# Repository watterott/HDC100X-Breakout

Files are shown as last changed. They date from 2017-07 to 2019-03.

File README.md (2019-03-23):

# HDC100X-Breakout
Breakout with TI HDC1000 or HDC1008 Digital Humidity and Temperature Sensor.

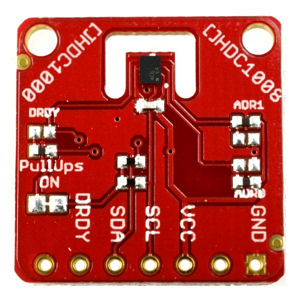
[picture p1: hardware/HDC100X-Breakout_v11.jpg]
HDC100X-Breakout


* [TI HDC1000 or HDC1008](https://www.ti.com/product/hdc1008) Digital Humidity and Temperature Sensor
* Relative Humidity (RH) operating range: 0% to 100%
* Relative Humidity accuracy: HDC1008 +/-4%, HDC1000 +/-3%
* Temperature accuracy: +/-0.2°C
* TWI/I2C Interface (address: 0x43 with ADR0=1 and ADR1=1)
* 3.3V - 5V Power Supply and Logic Level
* Open-Source and released under the [Creative Commons Attribution Share-Alike License](https://creativecommons.org/licenses/by-sa/4.0/).
* **[Documentation on learn.watterott.com](https://learn.watterott.com)**

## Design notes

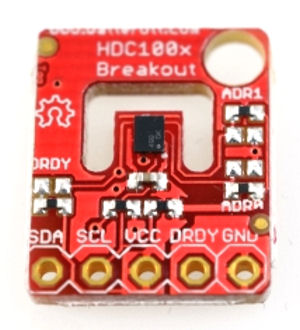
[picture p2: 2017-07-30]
hardware/HDC100X-Breakout_v10.jpg

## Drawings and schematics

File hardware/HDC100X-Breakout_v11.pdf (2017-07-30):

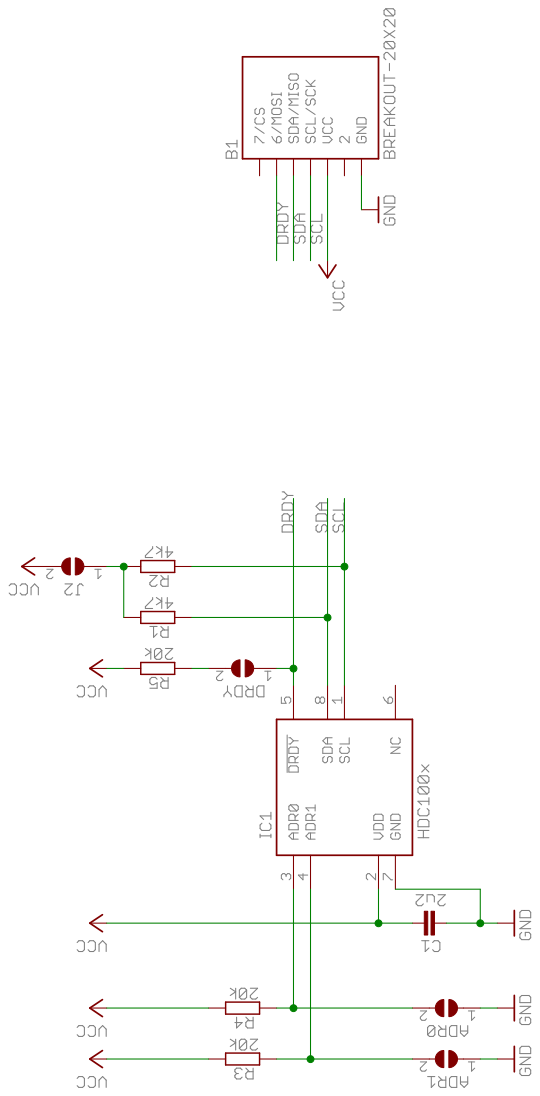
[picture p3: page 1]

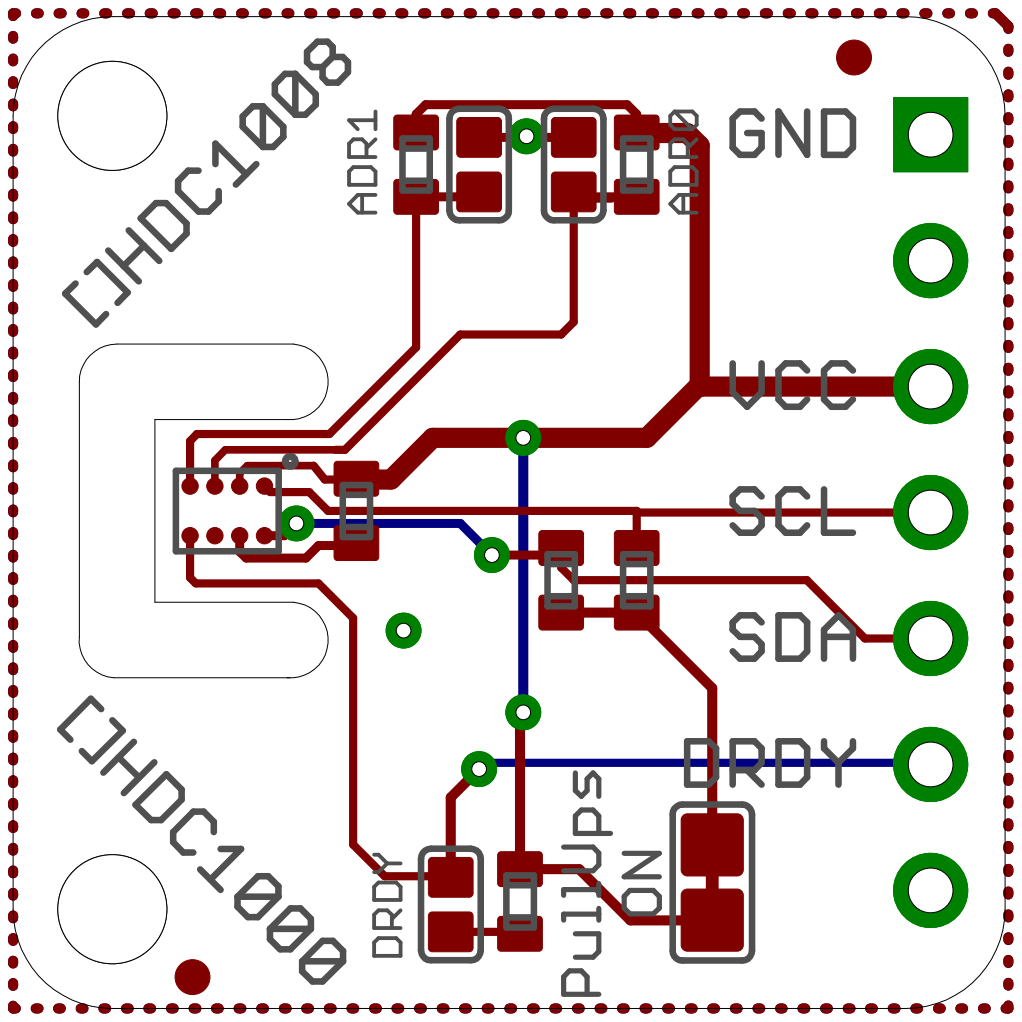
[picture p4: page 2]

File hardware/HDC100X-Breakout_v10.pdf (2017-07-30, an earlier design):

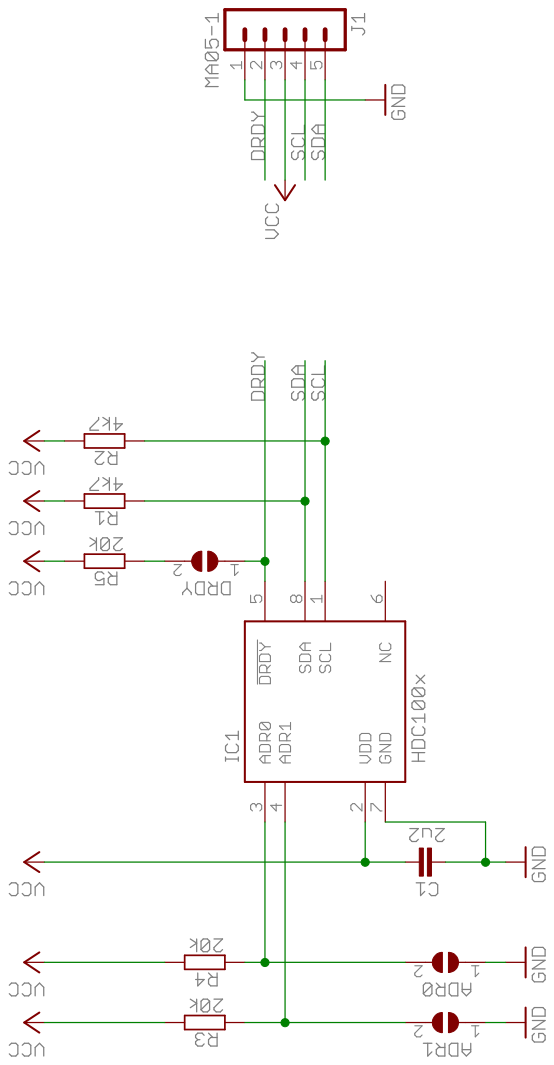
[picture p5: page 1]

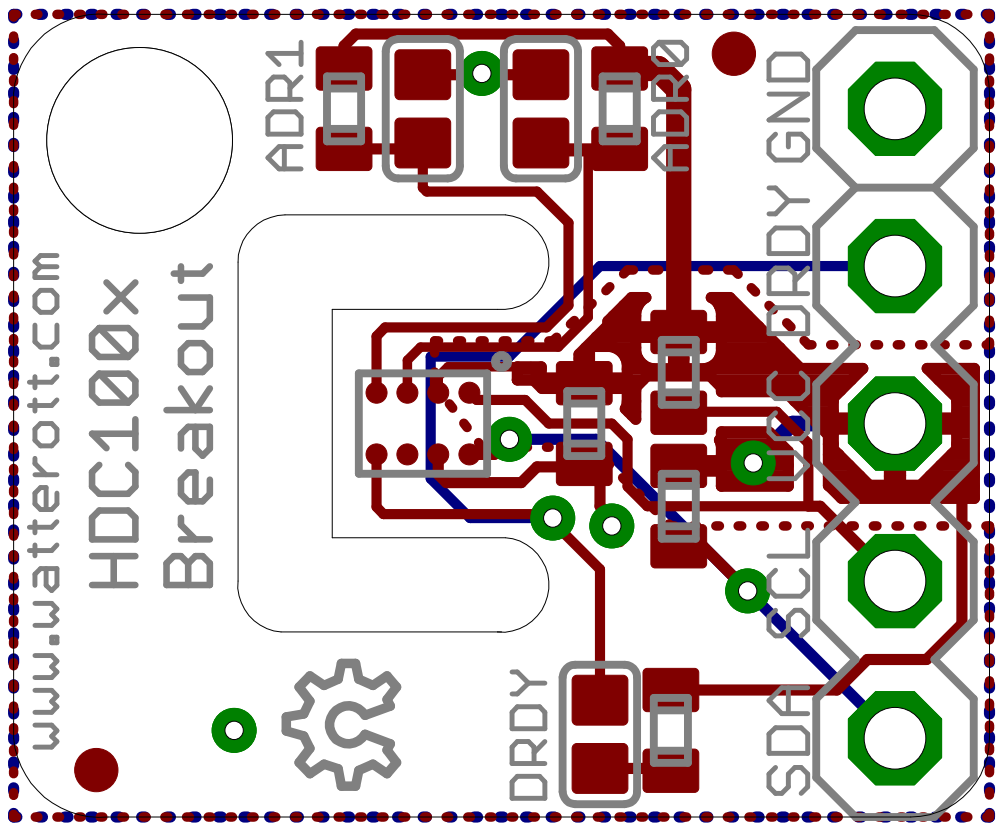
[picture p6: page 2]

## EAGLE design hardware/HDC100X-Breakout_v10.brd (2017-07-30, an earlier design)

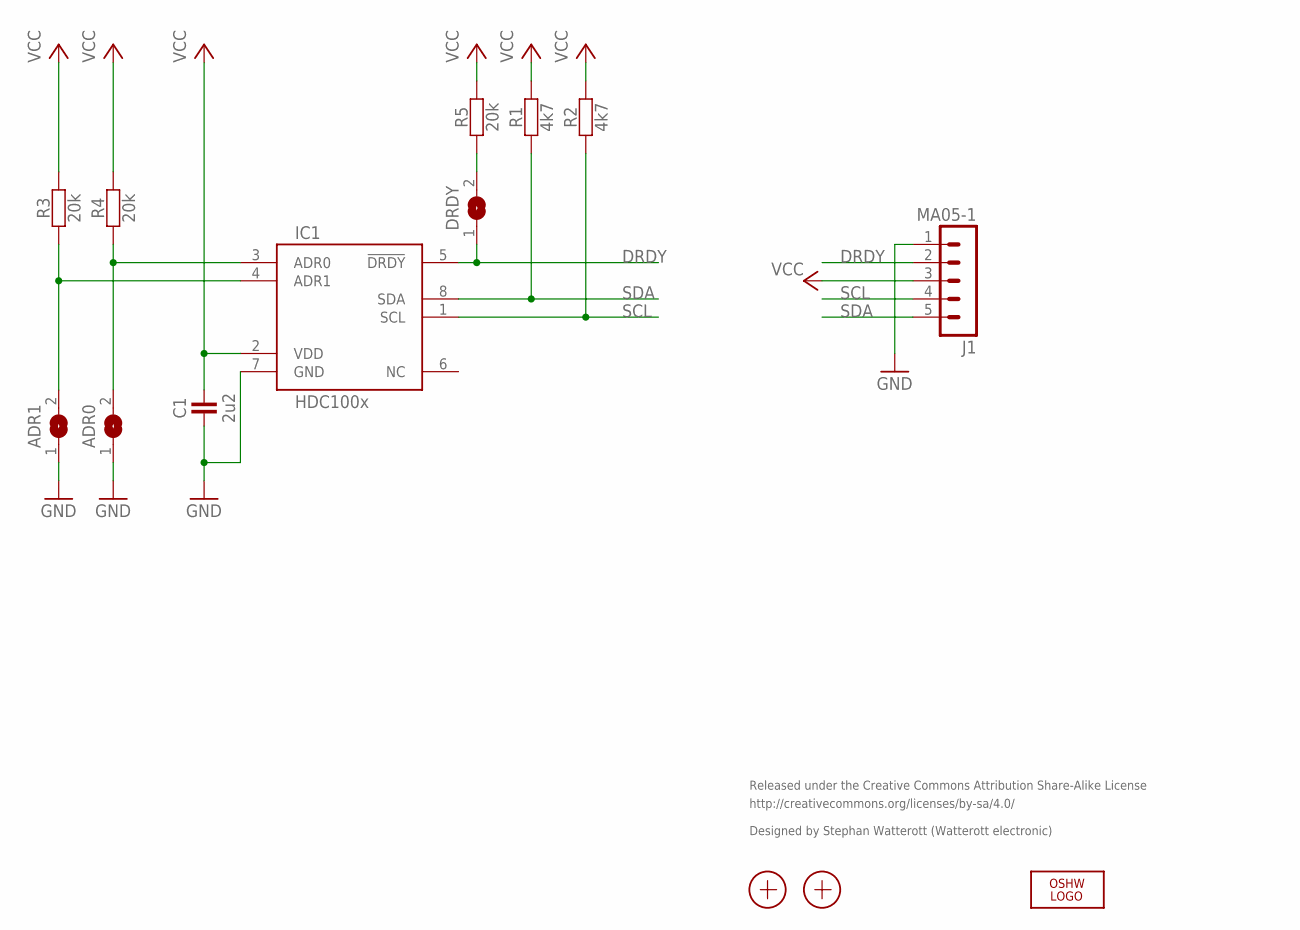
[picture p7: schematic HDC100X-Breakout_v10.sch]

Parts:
ADR0, ADR1: JUMPER2-0402
C1: 2u2; R0402
DRDY: JUMPER2-0402
IC1: HDC100x; WLCSP
J1: MA05-1
LOGO2: OSHW_LOGOX0070; OSHW_6X70
R1, R2: 4k7; R0402
R3, R4, R5: 20k; R0402
X1, X2: PASSER-07; PASSER_07MM

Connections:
ADR0: ADR0.2, IC1.3 (ADR0), R4.1
ADR1: ADR1.2, IC1.4 (ADR1), R3.1
DRDY: DRDY.1, IC1.5 (!DRDY), J1.2
GND: ADR0.1, ADR1.1, C1.1, IC1.7 (GND), J1.1
unnamed: DRDY.2, R5.1
SCL: IC1.1 (SCL), J1.4, R2.1
SDA: IC1.8 (SDA), J1.5, R1.1
VCC: C1.2, IC1.2 (VDD), J1.3, R1.2, R2.2, R3.2, R4.2, R5.2

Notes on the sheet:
Released under the Creative Commons Attribution Share-Alike License
http://creativecommons.org/licenses/by-sa/4.0/
Designed by Stephan Watterott (Watterott electronic)

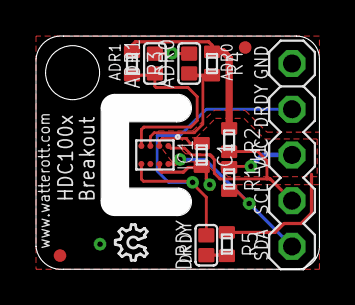
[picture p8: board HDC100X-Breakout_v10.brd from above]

Board: 2 copper layers, 15.7 x 13.0 mm, 14 parts (0 on the bottom side), 8 nets.

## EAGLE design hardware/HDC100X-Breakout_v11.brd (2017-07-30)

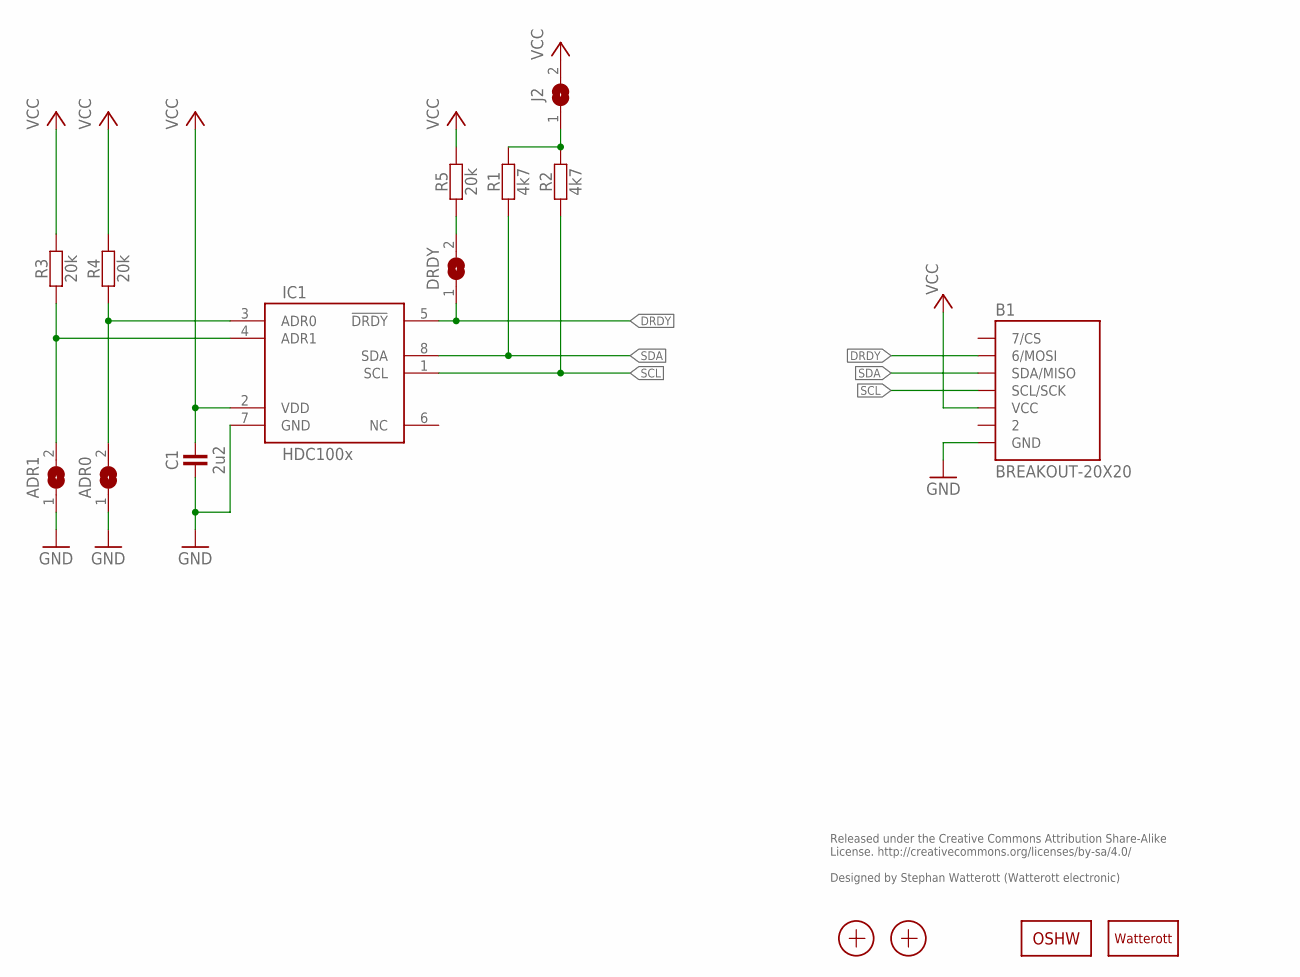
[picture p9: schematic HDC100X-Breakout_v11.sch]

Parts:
ADR0, ADR1: JUMPER2-0402
B1: BREAKOUT-20X20
C1: 2u2; R0402
DRDY: JUMPER2-0402
IC1: HDC100x; WLCSP
J2: JUMPER2-0603
LOGO2: OSHW_LOGOX0070; OSHW_6X70
LOGO3: LOGO-S_PLACE_M; SPARK_TPLACE_M
R1, R2: 4k7; R0402
R3, R4, R5: 20k; R0402
X1, X2: PASSER-07; PASSER_07MM

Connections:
ADR0: ADR0.2, IC1.3 (ADR0), R4.1
ADR1: ADR1.2, IC1.4 (ADR1), R3.1
DRDY: B1.MOSI (6/MOSI), DRDY.1, IC1.5 (!DRDY)
GND: ADR0.1, ADR1.1, B1.GND, C1.1, IC1.7 (GND)
unnamed: J2.1, R1.2, R2.2
unnamed: DRDY.2, R5.1
SCL: B1.SCL/SCK, IC1.1 (SCL), R2.1
SDA: B1.SDA/MISO, IC1.8 (SDA), R1.1
VCC: B1.VCC, C1.2, IC1.2 (VDD), J2.2, R3.2, R4.2, R5.2

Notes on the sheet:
Released under the Creative Commons Attribution Share-Alike License. http://creativecommons.org/licenses/by-sa/4.0/ Designed by Stephan Watterott (Watterott electronic)

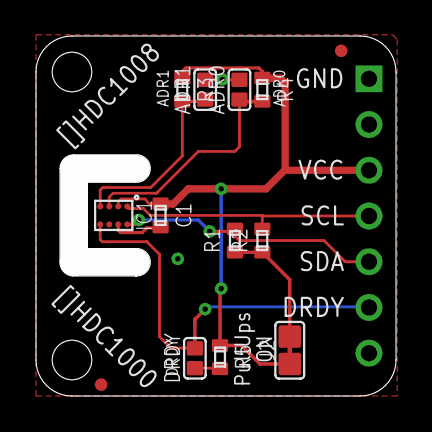
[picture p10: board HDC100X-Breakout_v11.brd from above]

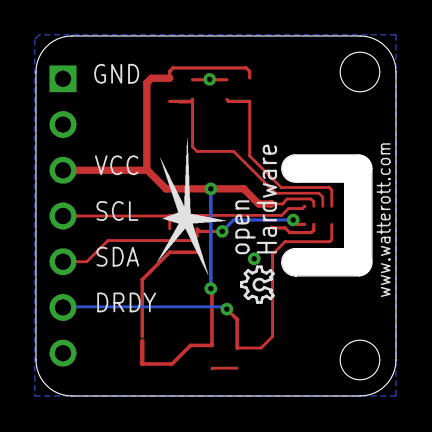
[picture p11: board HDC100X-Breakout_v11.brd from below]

Board: 2 copper layers, 20.0 x 20.0 mm, 16 parts (2 on the bottom side), 9 nets.
